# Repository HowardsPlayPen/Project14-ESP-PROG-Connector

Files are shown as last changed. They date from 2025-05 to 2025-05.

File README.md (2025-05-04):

# Project14-ESP-PROG-Connector

Helper board to allow connecting to ESP32 boards easier - i.e. from PlatformIO I can connect via the USB-C to access this helper boards FTDI chip to then connect onwards to whatever ESP32 I am developing at the time

It allows a Tag Connect cable (TDC2050) to connect to the ESP32 board 

As the connector is 10 pins I could include the power + TX/RX + Boot/Reset also the pins needed for hardware debugging on the same connector. I googled to see if I could find standardised pins for this sort of thing but didnt have any luck, so just made my own.

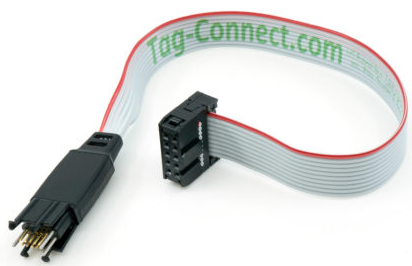
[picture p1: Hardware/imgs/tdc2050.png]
TDC 2050


OR

The board allows the same TDC2050 to be used - but along with an ESP32 debugging board

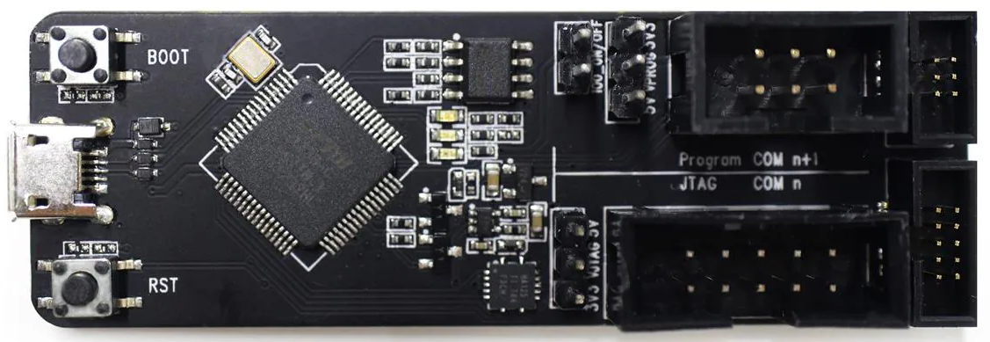
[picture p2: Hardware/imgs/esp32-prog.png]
ESP32-Prog hardware debugging board


(Only issue I have with the ESP32-Prog board is that it uses a micro-usb connector rather than a USB-C so I would expect that to really limit what power it can supply to my ESP32 board.)

## Simple screenshot of the PCB

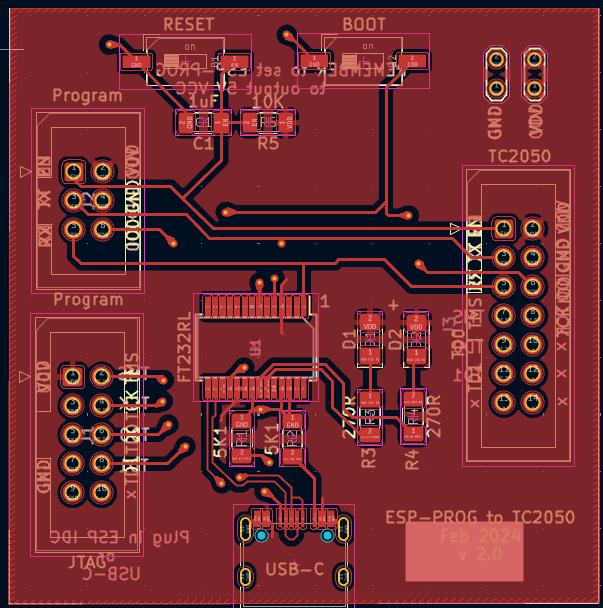
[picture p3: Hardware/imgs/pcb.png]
PCB view of Project


## Simple Kicad 3D representation of the board

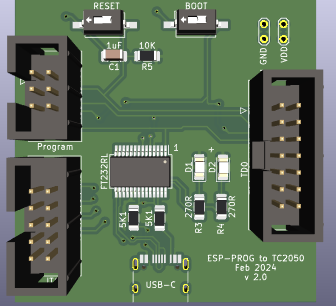
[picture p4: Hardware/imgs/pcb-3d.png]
Kicad PCB 3D view of Project


## Schematic of TDC 2050 connector on my ESP32 board

This is the schematic of the connector to put on the destination ESP32 board 

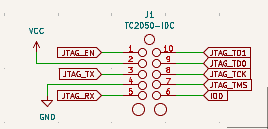
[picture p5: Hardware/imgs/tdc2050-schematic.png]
Schematic of connector to add to each project


Example of connecting this to an ESP32-CAM for both USB monitoring and hardware debugging

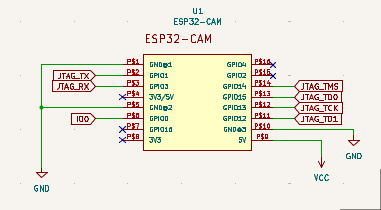
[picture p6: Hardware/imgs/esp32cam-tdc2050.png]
Connecting the TDC2050 to an ESP32-CAM


## View of the project

I am used to having RX + TX pins on my ESP32 boards or a USB-C connector - but with this project I can just add in the TDC-2050 pinout and then when I want to debug the board it is a simple connection to my PC. I can even hardware debug using the same connector.

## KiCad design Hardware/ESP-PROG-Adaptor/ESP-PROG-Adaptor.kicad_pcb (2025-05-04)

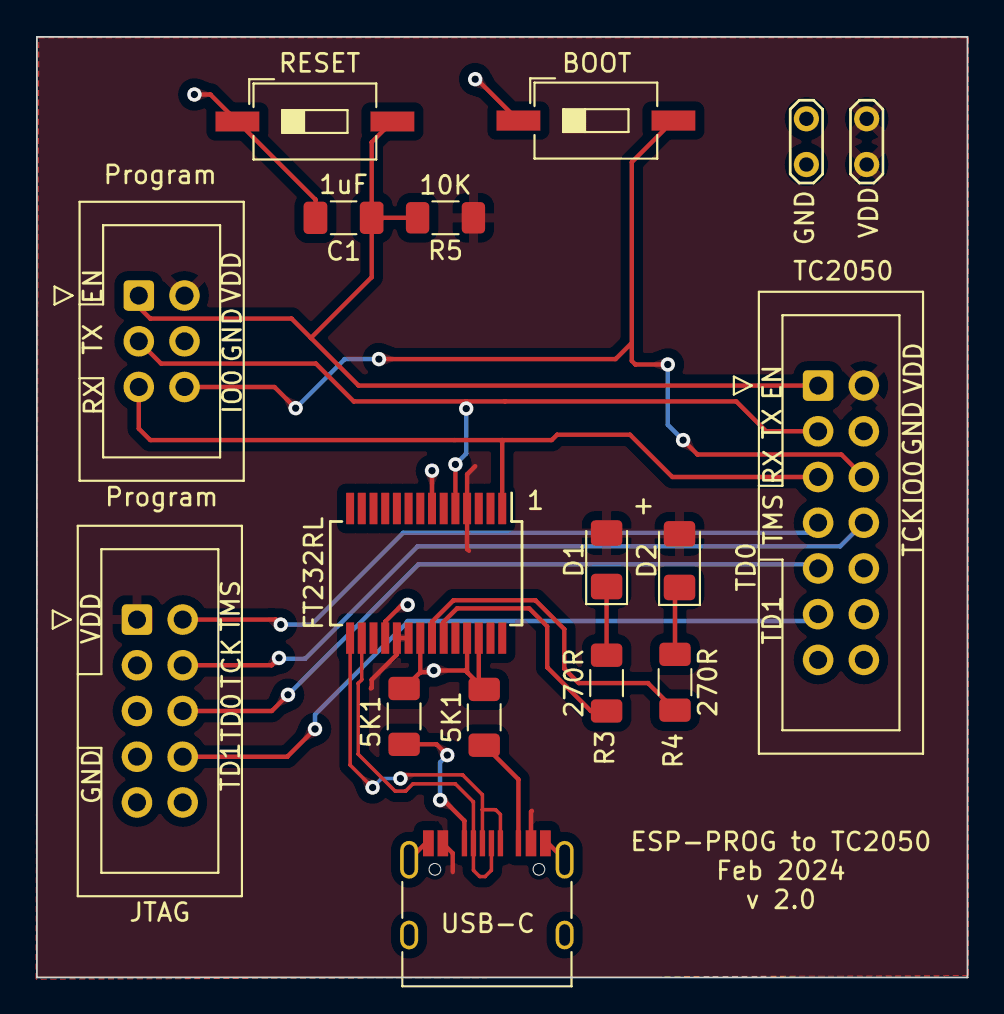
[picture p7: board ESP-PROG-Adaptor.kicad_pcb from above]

Board: 2 copper layers, 51.7 x 52.2 mm, 17 parts (0 on the bottom side), 18 nets.

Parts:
B1: RESET; SW_DIP_SPSTx01_Slide_6.7x4.1mm_W8.61mm_P2.54mm_LowProfile
B2: BOOT; SW_DIP_SPSTx01_Slide_6.7x4.1mm_W8.61mm_P2.54mm_LowProfile
C1: 1uF; C_1206_3216Metric_Pad1.33x1.80mm_HandSolder
D1, D2: LED; LED_1206_3216Metric_Pad1.42x1.75mm_HandSolder
GND1: GND; TestPoint_2Pads_Pitch2.54mm_Drill0.8mm
J1: JTAG; IDC-Header_2x05_P2.54mm_Vertical
J2: Program; IDC-Header_2x03_P2.54mm_Vertical
J3: TDC2050_Connector; IDC-Header_2x07_P2.54mm_Vertical
J4: USB_C_Receptacle_USB2.0; USB_C_Receptacle_HRO_TYPE-C-31-M-12
R1, R2: 5K1; R_1206_3216Metric_Pad1.30x1.75mm_HandSolder
R3, R4: 270R; R_1206_3216Metric_Pad1.30x1.75mm_HandSolder
R5: 10K; R_1206_3216Metric_Pad1.30x1.75mm_HandSolder
U1: FT232RL; SSOP-28_5.3x10.2mm_P0.65mm
VCC1: VCC; TestPoint_2Pads_Pitch2.54mm_Drill0.8mm

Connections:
D+: J4.A6 (D+), J4.B6 (D+), U1.15 (USBD+)
D-: J4.A7 (D-), J4.B7 (D-), U1.16 (USBD-)
EN: B1.2, C1.1, J2.1, J3.1, R5.2
ESP_TCK: J1.4, J3.8
ESP_TD0: J1.6, J3.9
ESP_TD1: J1.8, J3.11
ESP_TMS: J1.2, J3.7
GND: B1.1, B2.1, C1.2, GND1.1, GND1.2, J1.3, J1.5, J1.7, J1.9, J2.4, J3.4, J4.A1 (GND), J4.A12 (GND), J4.B1 (GND), J4.B12 (GND), J4.S1 (SHIELD), R1.1, R2.1, U1.7 (GND), U1.18 (GND), U1.21 (GND), U1.25 (AGND), U1.26 (TEST)
IO0: B2.2, J2.6, J3.6
unnamed: D1.1 (K), R3.1
unnamed: D2.1 (K), R4.2
unnamed: J4.A5 (CC1), R1.2
unnamed: J4.B5 (CC2), R2.2
unnamed: R3.2, U1.23 (CBUS0)
unnamed: R4.1, U1.22 (CBUS1)
RX: J2.5, J3.5, U1.1 (TXD)
TX: J2.3, J3.3, U1.5 (RXD)
VDD: D1.2 (A), D2.2 (A), J1.1, J2.2, J3.2, J4.A4 (VBUS), J4.A9 (VBUS), J4.B4 (VBUS), J4.B9 (VBUS), R5.1, U1.4 (VCCIO), U1.19 (~RESET), U1.20 (VCC), VCC1.1, VCC1.2
